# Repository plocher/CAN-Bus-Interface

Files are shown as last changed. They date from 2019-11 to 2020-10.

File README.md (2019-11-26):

# Protoboard-CANBus
## License: CERN Open Hardware Licence v1.2

The CANBus Breadboard interface is a simple experimenter's interface
to the new, experimental CAN bus based NMRANet model railroad control
bus. It is similar to, and derived from the LEDuino, which (at this
writing) is no longer available.

## CANBus Breadboard Interface features

  * 5v power input taken from breadboard
  * A complete hardware interface to the industry standard CAN Bus
  * A single EuroStyle 4 pin commector (5v, H, L, Gnd)
  * Optional LED "RX", "TX", and "Interrupt" feedback
  * All MCP2551 communication pins available for connection to appropriate processor input and output pins.

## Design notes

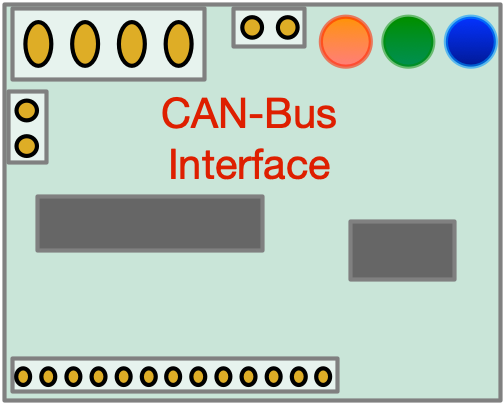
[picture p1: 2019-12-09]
CAN-Bus-Interface-Graphic.png

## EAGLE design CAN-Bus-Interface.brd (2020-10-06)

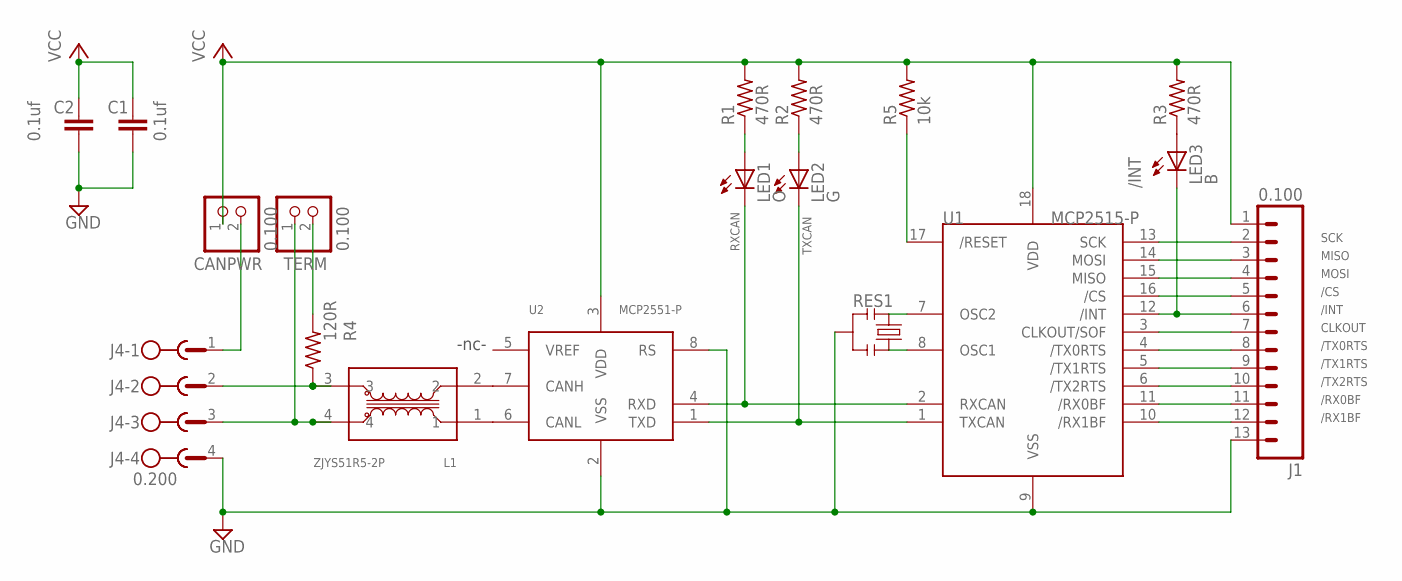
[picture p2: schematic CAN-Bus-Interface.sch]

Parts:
C1, C2: 0.1uf; CAP-PTH-SMALL2
CANPWR: 0.100; 1X02
J1: 0.100; 1X13
J4: 0.200; MSTBV4
L1: ZJYS51R5-2P; ZJYS
LED1: O; Q62902-B155
LED2: G; Q62902-B155
LED3: B; Q62902-B155
R1, R2, R3: 470R; 0204/5
R4: 120R; 0204/5
R5: 10k; 0204/5
RES1: RESONATORPTH; RESONATOR-PTH
TERM: 0.100; 1X02
U1: MCP2515-P; DIL18
U2: MCP2551-P; DIL08

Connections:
/CS: J1.5, U1.16 (/CS)
/INT: J1.6, LED3.A (C), U1.12 (/INT)
/RESET: R5.1, U1.17 (/RESET)
/RX0BF: J1.11, U1.11 (/RX0BF)
/RX1BF: J1.12, U1.10 (/RX1BF)
/TX0RTS: J1.8, U1.4 (/TX0RTS)
/TX1RTS: J1.9, U1.5 (/TX1RTS)
/TX2RTS: J1.10, U1.6 (/TX2RTS)
CLKOUT: J1.7, U1.3 (CLKOUT/SOF)
GND: C1.2, C2.2, J1.13, J4.4, RES1.2, U1.9 (VSS), U2.2 (VSS), U2.8 (RS)
MISO: J1.3, U1.14 (MOSI)
MOSI: J1.4, U1.15 (MISO)
unnamed: CANPWR.2, J4.1
unnamed: L1.1, U2.6 (CANL)
unnamed: L1.2, U2.7 (CANH)
unnamed: J4.2, L1.3, R4.1
unnamed: J4.3, L1.4, TERM.1
unnamed: R4.2, TERM.2
unnamed: LED1.K (A), R1.1
unnamed: LED2.K (A), R2.1
unnamed: LED3.K (A), R3.1
OSC1: RES1.3, U1.8 (OSC1)
OSC2: RES1.1, U1.7 (OSC2)
RXCAN: LED1.A (C), U1.2 (RXCAN), U2.4 (RXD)
SCK: J1.2, U1.13 (SCK)
TXCAN: LED2.A (C), U1.1 (TXCAN), U2.1 (TXD)
VCC: C1.1, C2.1, CANPWR.1, J1.1, R1.2, R2.2, R3.2, R5.2, U1.18 (VDD), U2.3 (VDD)

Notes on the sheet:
-nc-

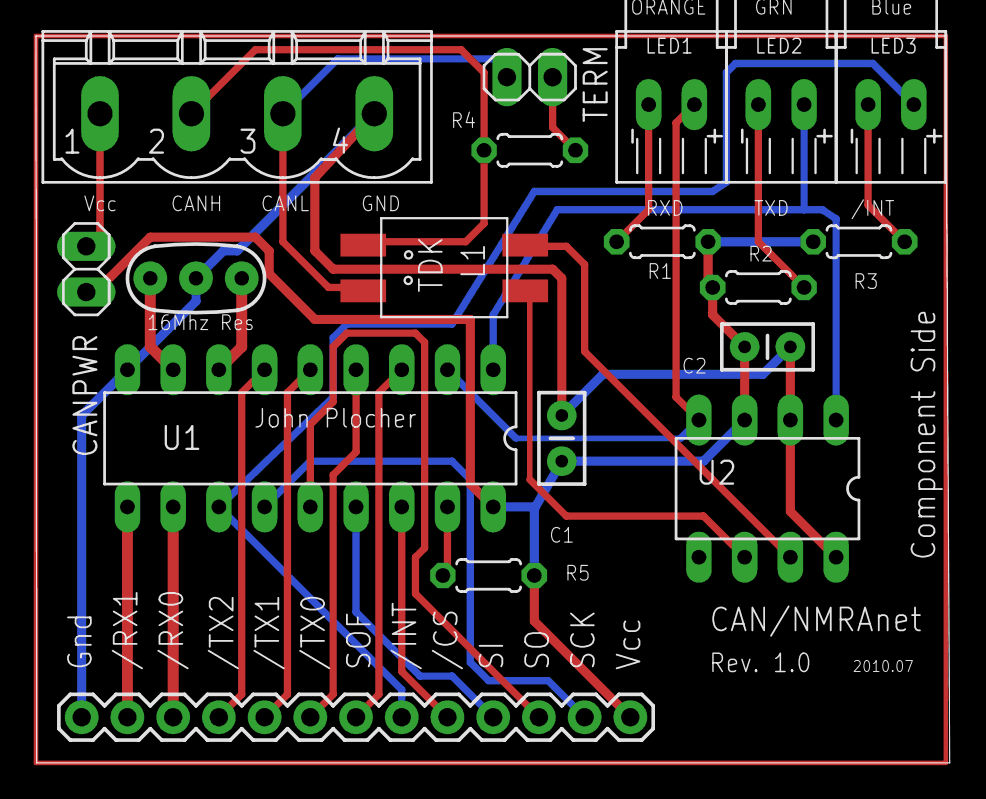
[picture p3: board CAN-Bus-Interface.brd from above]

Board: 2 copper layers, 50.8 x 40.4 mm, 18 parts (0 on the bottom side), 27 nets.

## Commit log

2020-10-05 added values for connectors
    [CAN-Bus-Interface.brd, CAN-Bus-Interface.sch]
2020-10-06 normalized values
    [CAN-Bus-Interface.brd, CAN-Bus-Interface.sch]
